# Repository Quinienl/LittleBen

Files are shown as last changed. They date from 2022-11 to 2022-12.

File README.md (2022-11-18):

# LittleBen
 LittleBen eurorack master clock
 
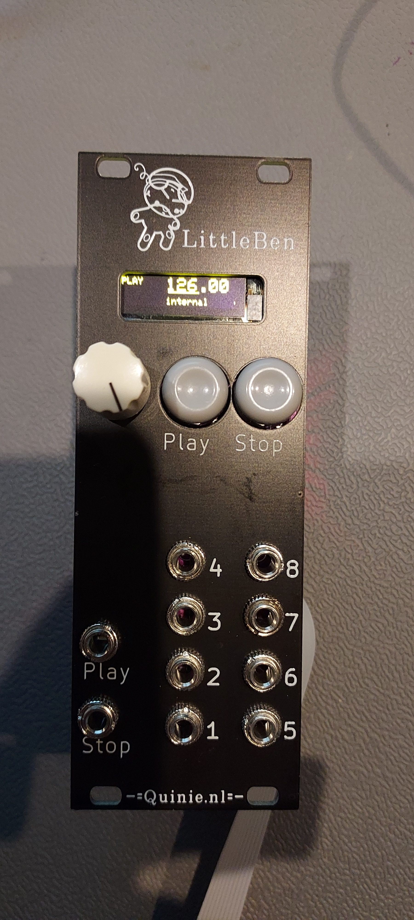
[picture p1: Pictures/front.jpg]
 

LittleBen is a masterclock for eurorack. It's based on a Arduino Mini. This is the second version. I decided to open source all files for this module. In this repo you will find all the files needed for making the pcb and panel for littleben. This files are created with Kicad 6.

This version has a few minor issues I would like to fix. 
- The panel has a hole for the lcd screen thats need a little bit more on the left side and a little less on the right side.

More info at:
https://www.quinie.nl/category/diy/littleben/

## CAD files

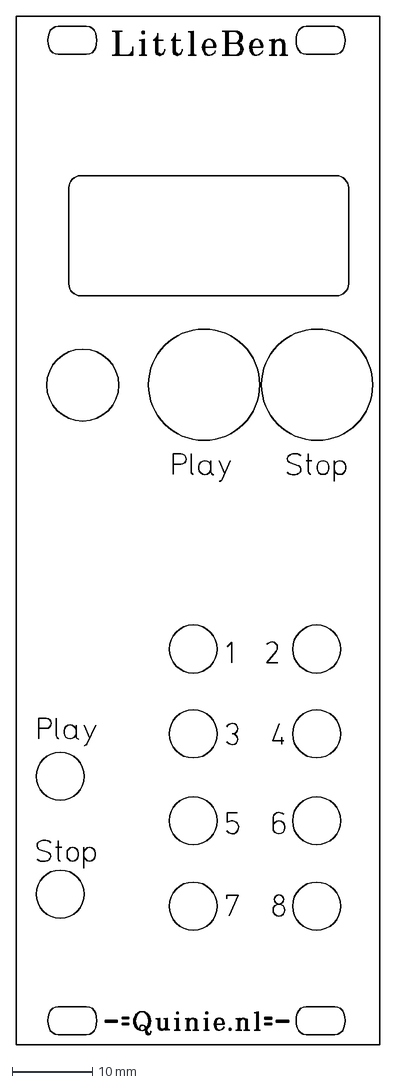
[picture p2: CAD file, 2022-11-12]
panel.dxf
45.4 x 128.4 mm

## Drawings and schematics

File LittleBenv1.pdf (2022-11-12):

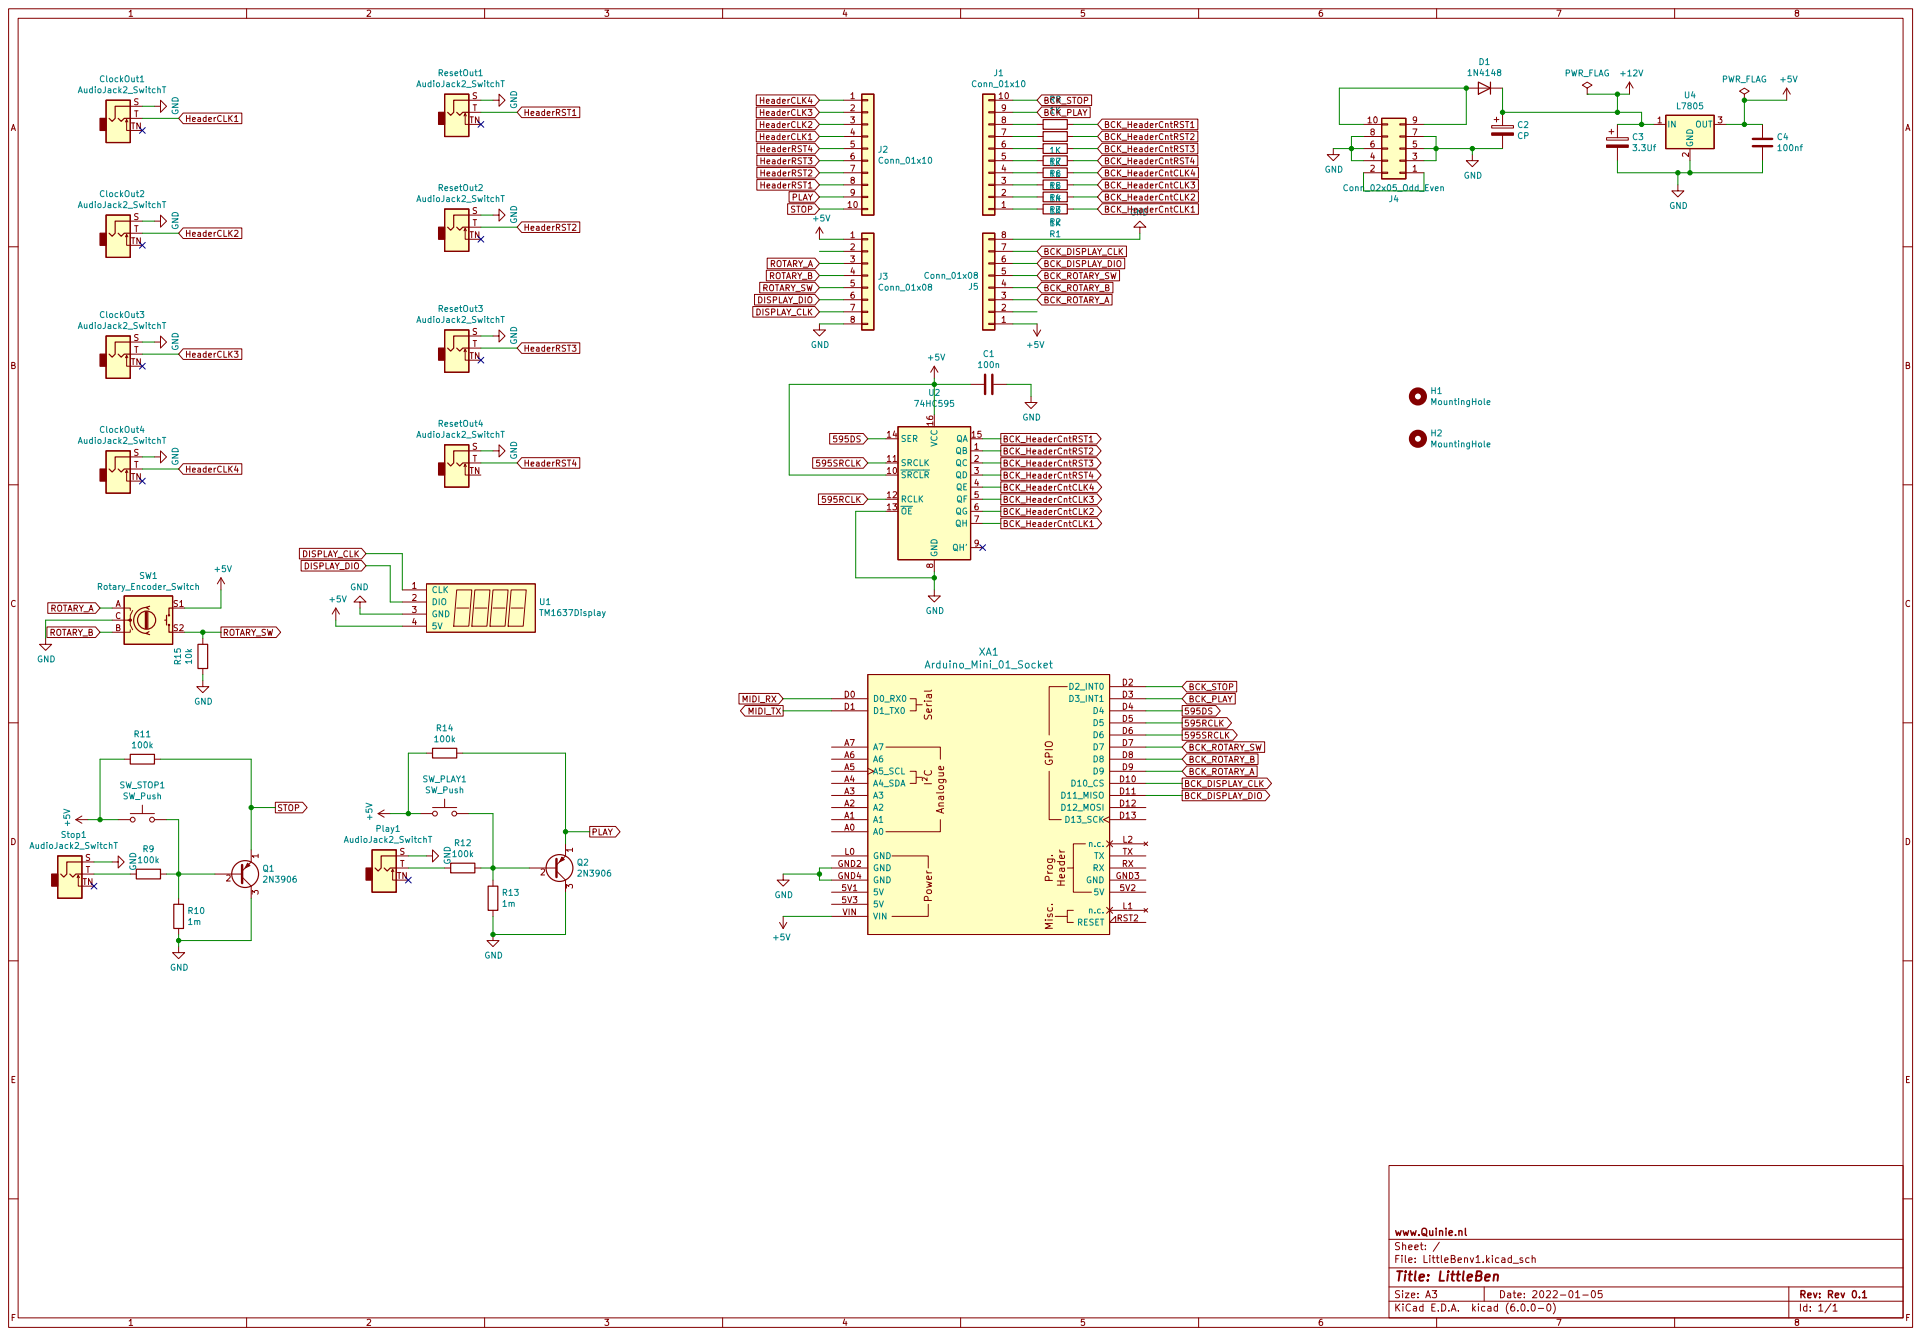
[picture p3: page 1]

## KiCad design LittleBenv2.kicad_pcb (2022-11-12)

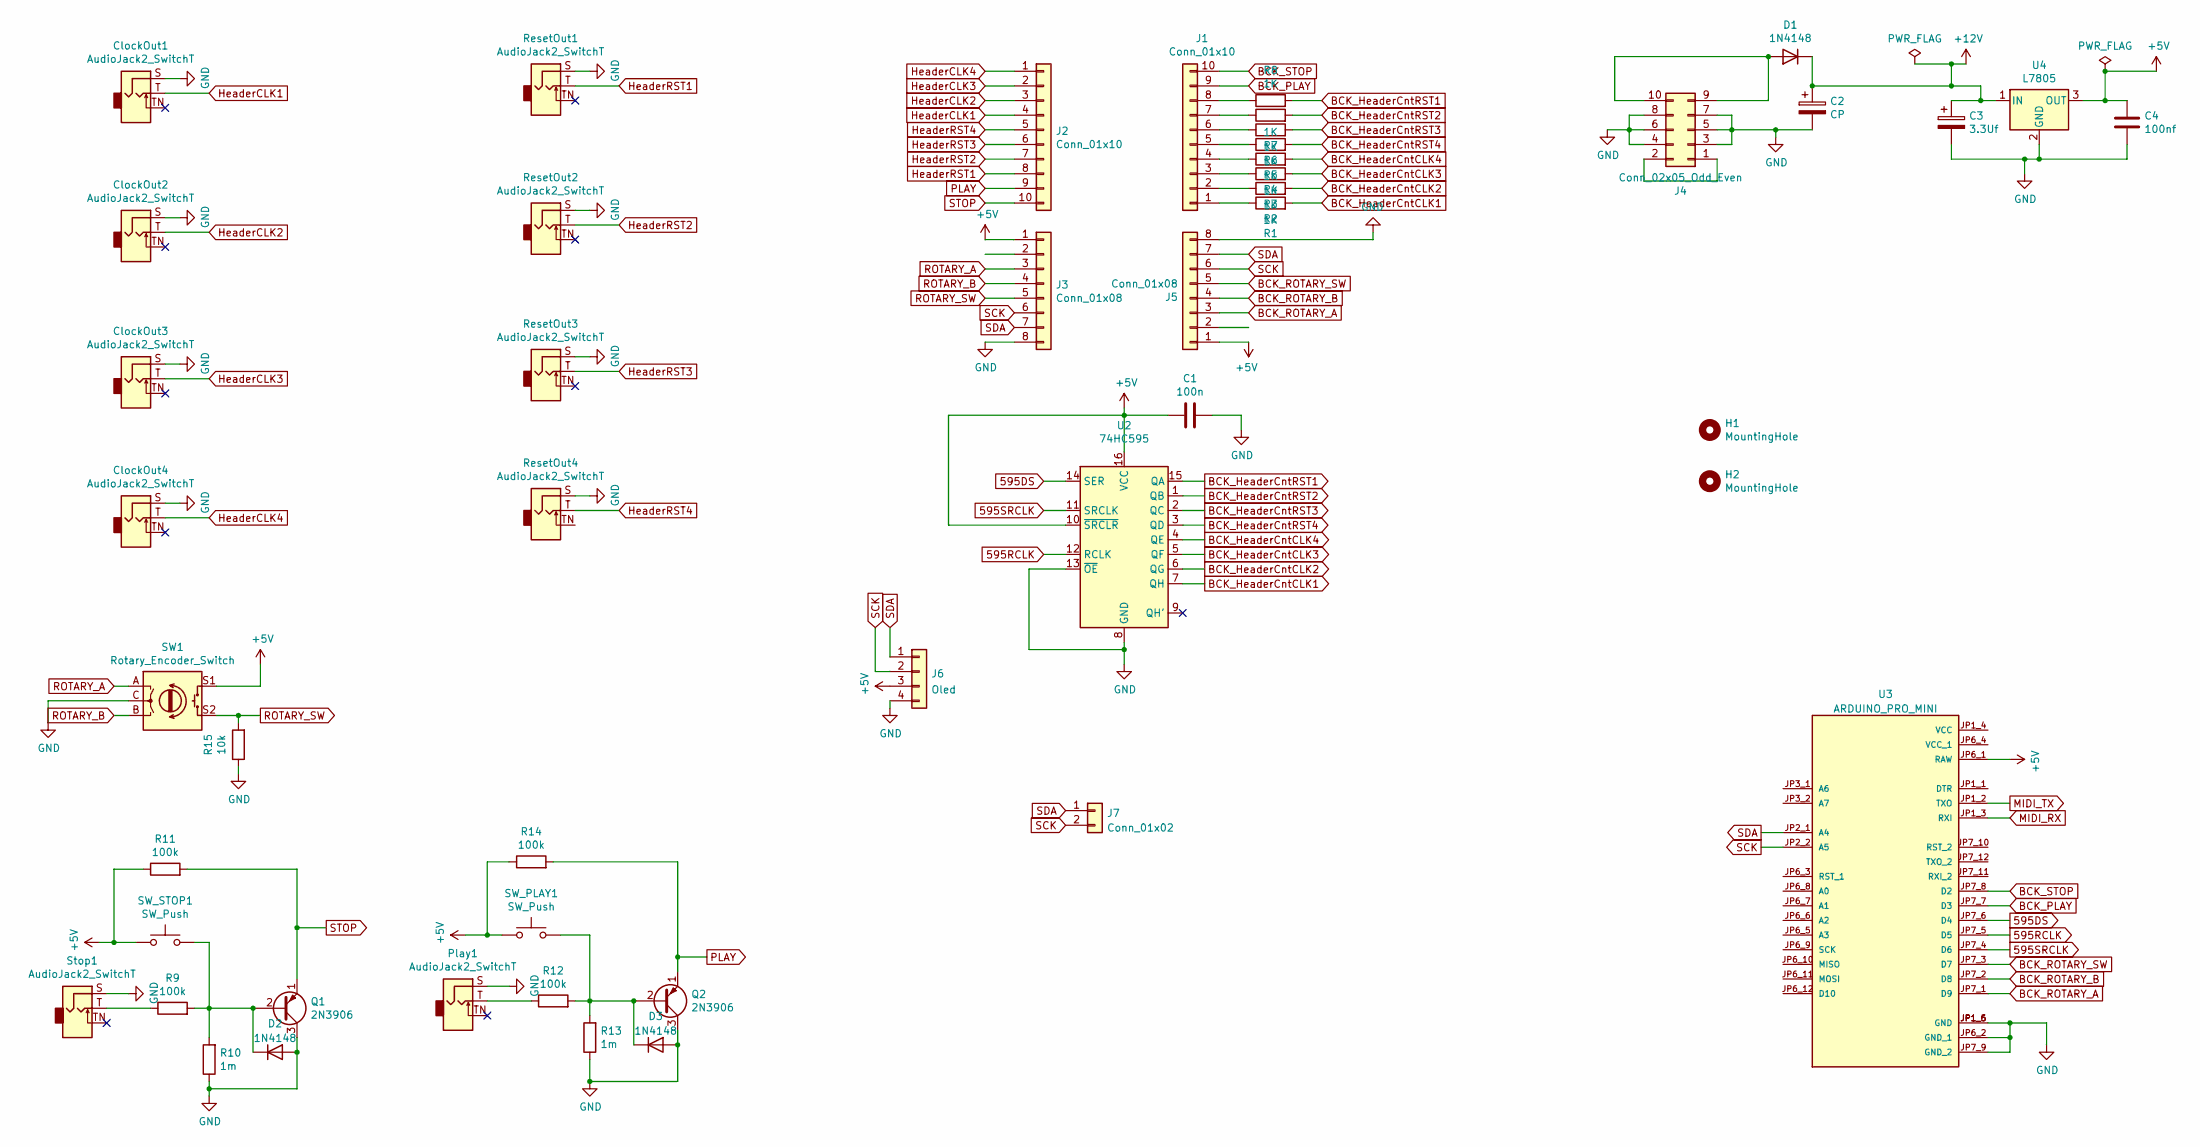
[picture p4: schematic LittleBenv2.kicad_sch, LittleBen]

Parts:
C1: 100n; C_Disc_D5.0mm_W2.5mm_P5.00mm
C2: CP; CP_Radial_D6.3mm_P2.50mm
C3: 3.3Uf; CP_Radial_D6.3mm_P2.50mm
C4: 100nf; C_Disc_D5.0mm_W2.5mm_P5.00mm
ClockOut1, ClockOut2, ClockOut3, ClockOut4: AudioJack2_SwitchT; Jack_3.5mm_QingPu_WQP-PJ398SM_Vertical_CircularHoles
D1, D2, D3: 1N4148; D_DO-35_SOD27_P7.62mm_Horizontal
H1, H2: MountingHole; MountingHole_3mm
J1: Conn_01x10; PinHeader_1x10_P2.54mm_Vertical
J2: Conn_01x10; PinSocket_1x10_P2.54mm_Vertical
J3: Conn_01x08; PinSocket_1x08_P2.54mm_Vertical
J4: Conn_02x05_Odd_Even; IDC-Header_2x05_P2.54mm_Vertical
J5: Conn_01x08; PinHeader_1x08_P2.54mm_Vertical
J6: Oled; PinHeader_1x04_P2.54mm_Vertical
J7: Conn_01x02; PinHeader_1x02_P2.54mm_Vertical
Play1: AudioJack2_SwitchT; Jack_3.5mm_QingPu_WQP-PJ398SM_Vertical_CircularHoles
Q1, Q2: 2N3906; TO-92_Inline_Wide
R1, R2, R3, R4, R5, R6, R7, R8: 1K; R_Axial_DIN0207_L6.3mm_D2.5mm_P10.16mm_Horizontal
R9, R11, R12, R14: 100k; R_Axial_DIN0207_L6.3mm_D2.5mm_P10.16mm_Horizontal
R10, R13: 1m; R_Axial_DIN0207_L6.3mm_D2.5mm_P10.16mm_Horizontal
R15: 10k; R_Axial_DIN0207_L6.3mm_D2.5mm_P10.16mm_Horizontal
ResetOut1, ResetOut2, ResetOut3, ResetOut4: AudioJack2_SwitchT; Jack_3.5mm_QingPu_WQP-PJ398SM_Vertical_CircularHoles
SW1: Rotary_Encoder_Switch; RotaryEncoder_Alps_EC12E-Switch_Vertical_H20mm
SW_PLAY1: SW_Push; TL2230
SW_STOP1: SW_Push; TL2230
Stop1: AudioJack2_SwitchT; Jack_3.5mm_QingPu_WQP-PJ398SM_Vertical_CircularHoles
U2: 74HC595; DIP-16_W7.62mm
U3: ARDUINO_PRO_MINI; MODULE_ARDUINO_PRO_MINI; PARTREV N/A
U4: L7805; TO-220-3_Vertical

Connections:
595DS: U2.14 (SER), U3.JP7_6 (D4)
595RCLK: U2.12 (RCLK), U3.JP7_5 (D5)
595SRCLK: U2.11 (SRCLK), U3.JP7_4 (D6)
+5V: C1.2, C4.1, J3.1, J5.1, J6.3, R11.1, R14.1, SW1.S1, SW_PLAY1.1, SW_STOP1.1, U2.10 (~SRCLR), U2.16 (VCC), U3.JP6_1 (RAW), U4.3 (OUT)
+12V: C2.1, C3.1, D1.1 (K), U4.1 (IN)
BCK_HeaderCntCLK1: R1.2, U2.7 (QH)
BCK_HeaderCntCLK2: R2.2, U2.6 (QG)
BCK_HeaderCntCLK3: R3.2, U2.5 (QF)
BCK_HeaderCntCLK4: R4.2, U2.4 (QE)
BCK_HeaderCntRST1: R8.2, U2.15 (QA)
BCK_HeaderCntRST2: R7.2, U2.1 (QB)
BCK_HeaderCntRST3: R6.2, U2.2 (QC)
BCK_HeaderCntRST4: R5.2, U2.3 (QD)
BCK_PLAY: J1.9, U3.JP7_7 (D3)
BCK_ROTARY_A: J5.3, U3.JP7_1 (D9)
BCK_ROTARY_B: J5.4, U3.JP7_2 (D8)
BCK_ROTARY_SW: J5.5, U3.JP7_3 (D7)
BCK_STOP: J1.10, U3.JP7_8 (D2)
GND: C1.1, C2.2, C3.2, C4.2, ClockOut1.S, ClockOut2.S, ClockOut3.S, ClockOut4.S, D2.2 (A), D3.2 (A), J3.8, J4.3, J4.4, J4.5, J4.6, J4.7, J4.8, J5.8, J6.4, Play1.S, Q1.3 (C), Q2.3 (C), R10.1, R13.1, R15.1, ResetOut1.S, ResetOut2.S, ResetOut3.S, ResetOut4.S, SW1.C, Stop1.S, U2.8 (GND), U2.13 (~OE), U3.JP1_5 (GND), U3.JP1_6 (GND), U3.JP6_2 (GND_1), U3.JP7_9 (GND_2), U4.2 (GND)
HeaderCLK1: ClockOut1.T, J2.4
HeaderCLK2: ClockOut2.T, J2.3
HeaderCLK3: ClockOut3.T, J2.2
HeaderCLK4: ClockOut4.T, J2.1
HeaderRST1: J2.8, ResetOut1.T
HeaderRST2: J2.7, ResetOut2.T
HeaderRST3: J2.6, ResetOut3.T
HeaderRST4: J2.5, ResetOut4.T
MIDI_RX: U3.JP1_3 (RXI)
MIDI_TX: U3.JP1_2 (TXO)
unnamed: D1.2 (A), J4.9, J4.10
unnamed: J1.1, R1.1
unnamed: J1.2, R2.1
unnamed: J1.3, R3.1
unnamed: J1.4, R4.1
unnamed: J1.5, R5.1
unnamed: J1.6, R6.1
unnamed: J1.7, R7.1
unnamed: J1.8, R8.1
unnamed: J4.1, J4.2
unnamed: Play1.T, R12.1
unnamed: D2.1 (K), Q1.2 (B), R9.2, R10.2, SW_STOP1.2
unnamed: D3.1 (K), Q2.2 (B), R12.2, R13.2, SW_PLAY1.2
unnamed: R9.1, Stop1.T
PLAY: J2.9, Q2.1 (E), R14.2
ROTARY_A: J3.3, SW1.A
ROTARY_B: J3.4, SW1.B
ROTARY_SW: J3.5, R15.2, SW1.S2
SCK: J3.6, J5.6, J6.2, J7.2, U3.JP2_2 (A5)
SDA: J3.7, J5.7, J6.1, J7.1, U3.JP2_1 (A4)
STOP: J2.10, Q1.1 (E), R11.2

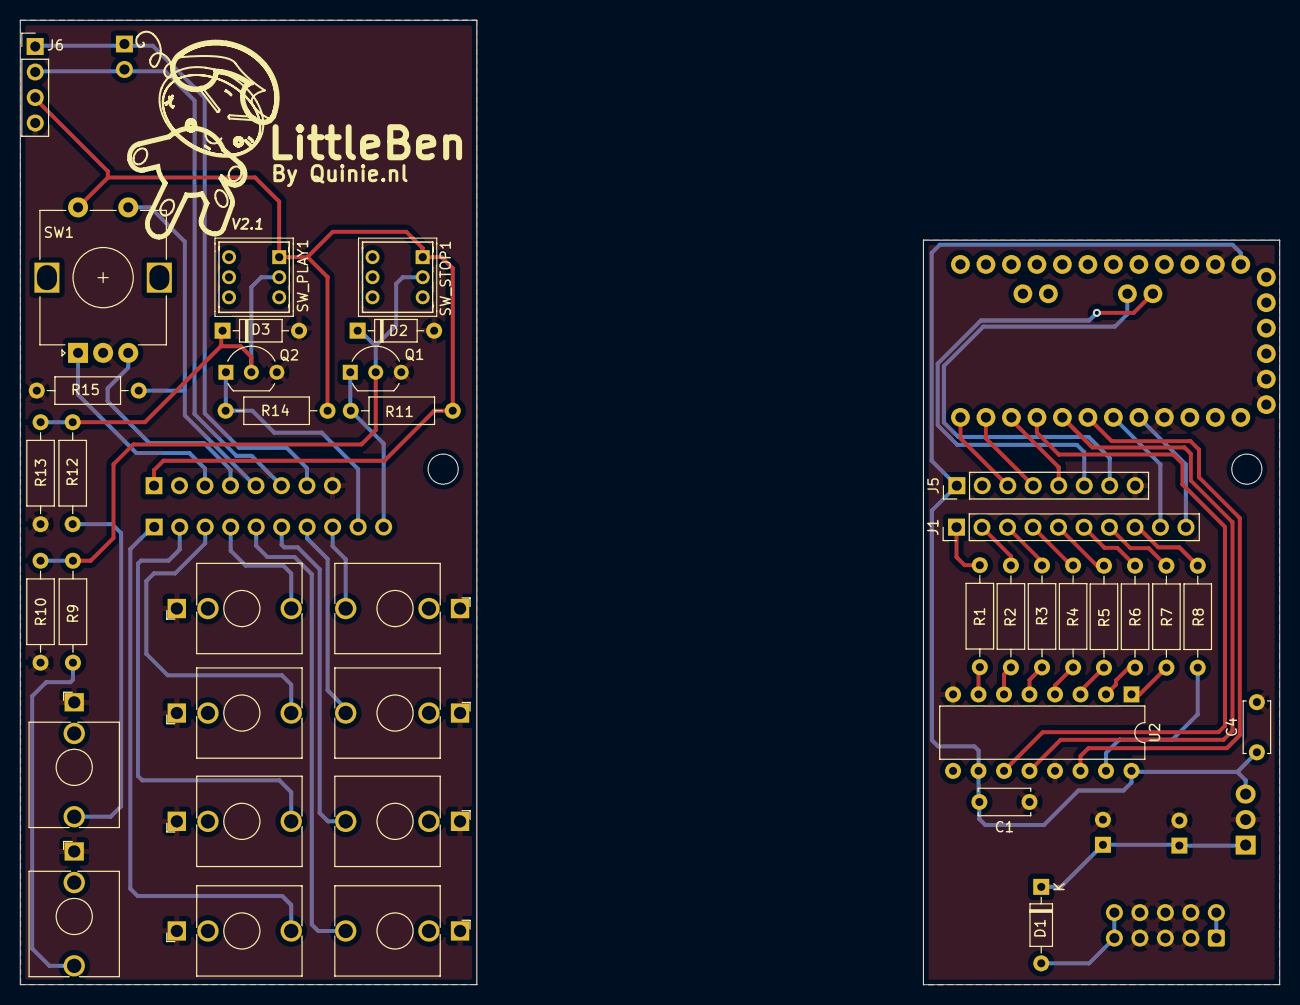
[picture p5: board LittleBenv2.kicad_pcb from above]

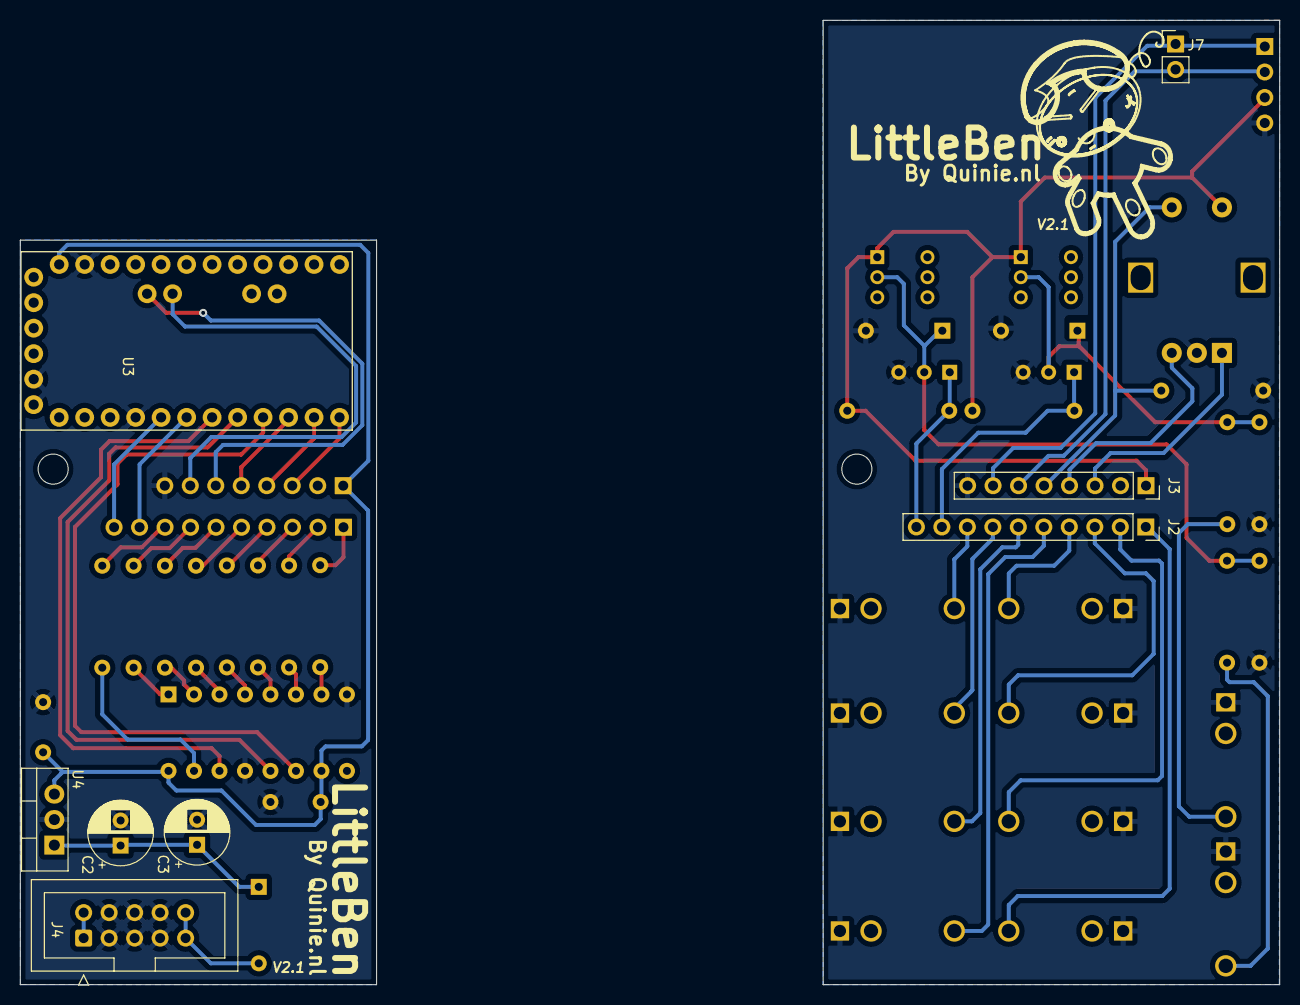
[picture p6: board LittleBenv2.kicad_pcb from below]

Board: 2 copper layers, 125.5 x 96.1 mm, 49 parts (8 on the bottom side), 48 nets.

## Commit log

2022-11-12 Opensourcing Littleben
    First upload
    [LittleBenPanel.kicad_pcb, LittleBenv2.kicad_pcb, LittleBenv2.kicad_sch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]
2022-11-18 Panel Update
    [LittleBenPanelv2-B_Cu.gbr, LittleBenPanelv2-B_Mask.gbr, LittleBenPanelv2-B_Paste.gbr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]
